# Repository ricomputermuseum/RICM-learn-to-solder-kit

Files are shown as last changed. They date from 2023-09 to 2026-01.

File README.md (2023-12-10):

# RICM-learn-to-solder-kit
These badges were designed as a soldering demo for the Rhode Island Computer Museum (RICM). They were designed to teach the basics of thru-hole soldering, as well as to provide users with a take home wearable. 
 
## Goals for this kit:
* A beginner kit for learning to solder.
* A simple circuit, 2 LEDS and a battery, but still interactive.
* Low cost, suitable for scout troops, school classes, summer camps, etc. Depending on order volume, parts will cost $2-4 per badge.

## Assembly instructions:
1. Solder the battery clip onto the exposed pads on the back of the board. Note that the battery clip used in this design is surface mount and considerably more difficult to solder than the other components. Depending on the audience it may be desirable for the instructor to solder this component before passing them out. 
2. Flip the board over and solder all other components to the front. Resistor values and transistor orientation are printed on the silkscreen.
3. Insert battery into clip and turn on switch. Hold hand over photoresistor to light up LEDS

## Parts list:
1x printed circuit board.
1x 47KΩ resistor (1/4W 5% carbon-film)
2x 220Ω resistors (1/4W 5% carbon-film)
1x NPN transistor (2N3904 or similar NPN (BC547,2N2222 etc.), TO-92-3 Kinked Lead)
2x light-emitting diodes (5mm, any color as desired)
1x SPDT mini slide switch (Shouhan SS-12D07VG3 or similar)
1x battery holder (Keystone 3002, 20mm coin cell, surface mount)
1x CR2032 Battery (3V, 20x3.2mm, 200mA)

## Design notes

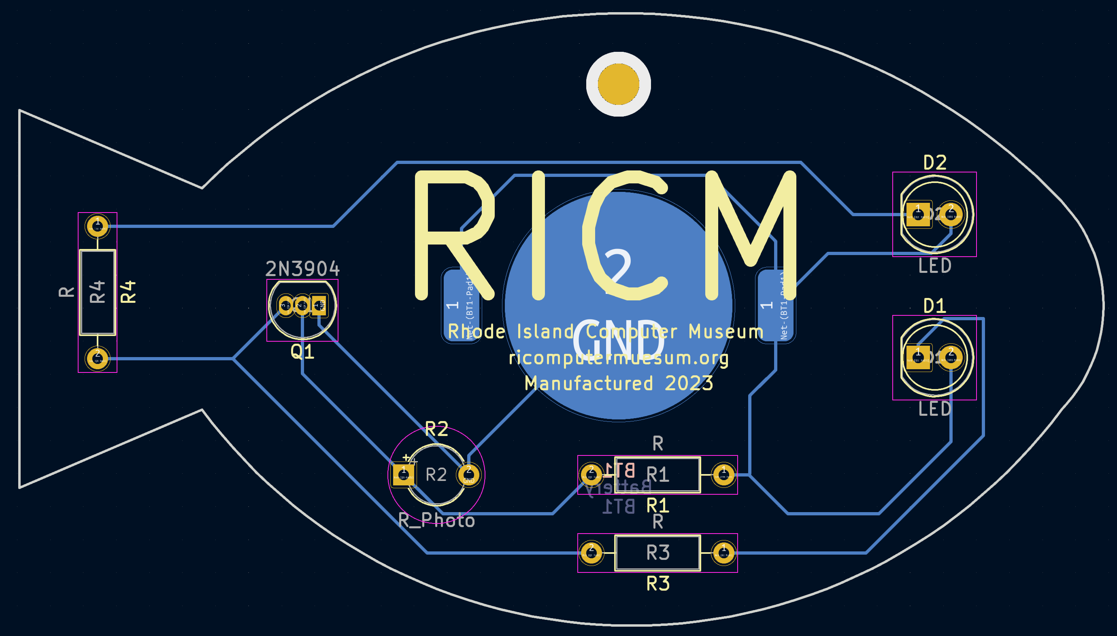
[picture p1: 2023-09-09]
image.png

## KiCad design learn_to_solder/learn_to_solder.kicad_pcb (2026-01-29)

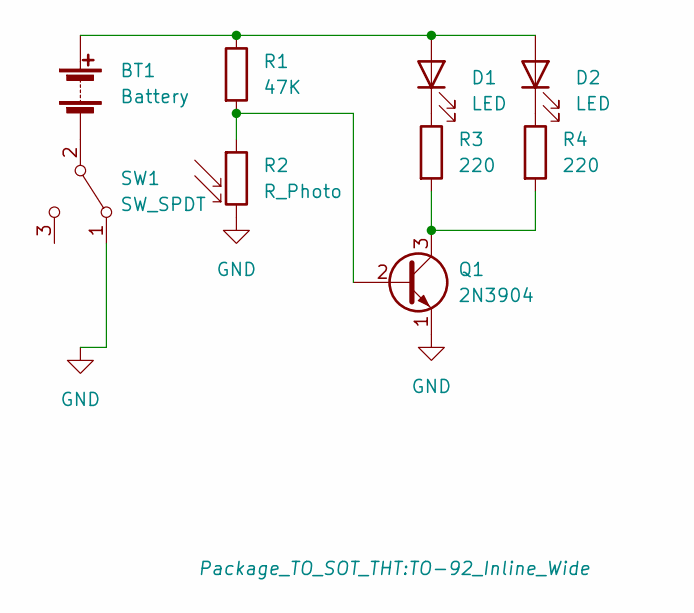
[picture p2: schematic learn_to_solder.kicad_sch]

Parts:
BT1: Battery; CR2032 retainer
D1, D2: LED; LED_D5.0mm
Q1: 2N3904; TO-92_Inline_Wide
R1: 47K; R_Axial_DIN0207_L6.3mm_D2.5mm_P10.16mm_Horizontal
R2: R_Photo; CP_Radial_Tantal_D4.5mm_P5.00mm
R3, R4: 220; R_Axial_DIN0207_L6.3mm_D2.5mm_P10.16mm_Horizontal
SW1: SW_SPDT; SW_Slide_1P2T_CK_OS102011MS2Q

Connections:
GND: Q1.1 (E), R2.2, SW1.1 (A)
unnamed: BT1.1 (+), D1.2 (A), D2.2 (A), R1.1
unnamed: BT1.2 (-), SW1.2 (B)
unnamed: D1.1 (K), R3.1
unnamed: D2.1 (K), R4.1
unnamed: Q1.2 (B), R1.2, R2.1
unnamed: Q1.3 (C), R3.2, R4.2

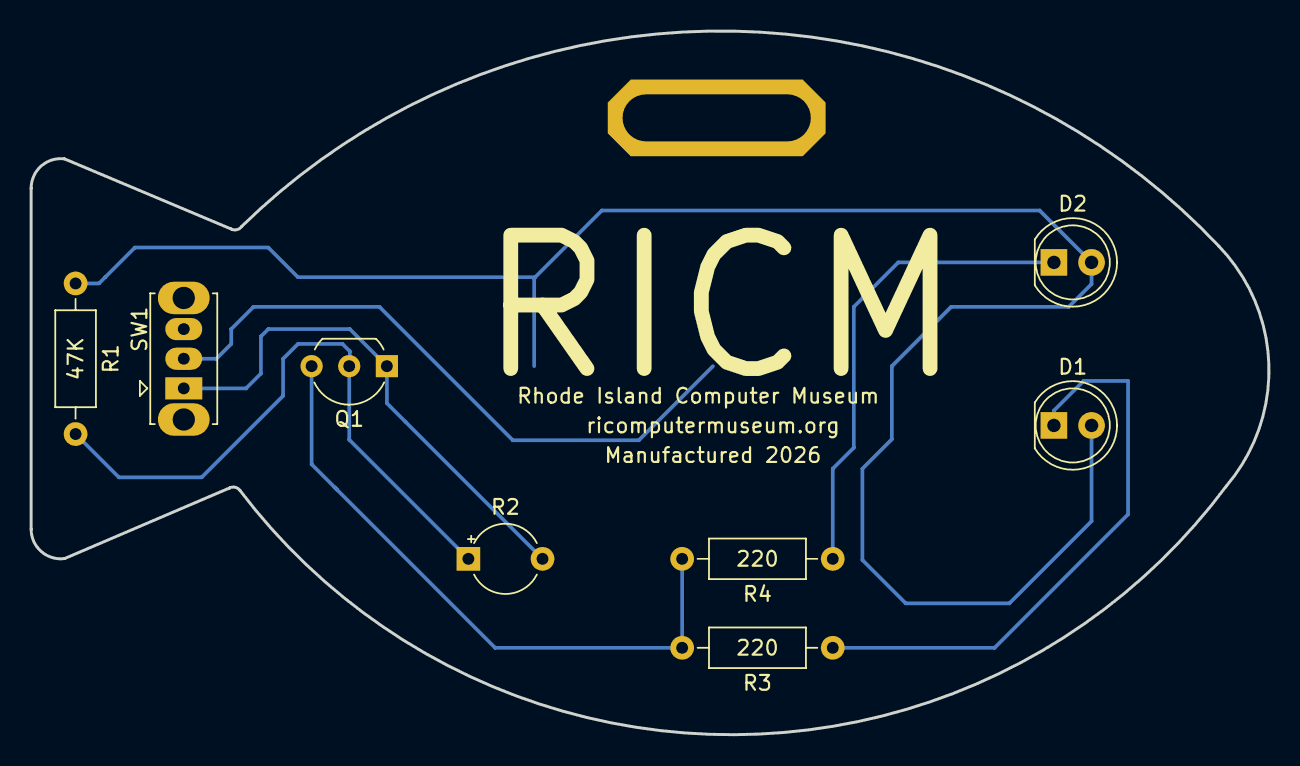
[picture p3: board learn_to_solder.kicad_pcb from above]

Board: 2 copper layers, 83.5 x 47.5 mm, 9 parts (1 on the bottom side), 7 nets.

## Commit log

2023-09-08 Added kicad files for first draft
    [learn_to_solder.kicad_pcb, learn_to_solder.kicad_sch]
2023-09-09 Create README.md
    RICM Learn to Solder Badge
2023-09-22 plotted gerbers
    [learn_to_solder_shrimp.kicad_pcb, learn_to_solder_shrimp.kicad_sch]
2023-09-22 Updated readme and silkscreen
    Updated readme to correctly reflect kit components. Added labels in front silkscreen with resistor values to make assembly easier. Rearranged resistors to put both 220s next to each other.
    [learn_to_solder.kicad_pcb, learn_to_solder.kicad_sch, learn_to_solder_shrimp.kicad_pcb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]
2023-12-10 V2 updates
    Rearranged resistors to group both 220s together. Added slide switch to turn off without removing battery. Corrected typos in silkscreen. Fixed clip slot size.
    [learn_to_solder.kicad_pcb, learn_to_solder.kicad_sch]
2026-01-29 v3 edits
    Filleted sharp board edge. Added slot footprint for hanger.
    [learn_to_solder-B_Cu.gbr, learn_to_solder-B_Mask.gbr, learn_to_solder-B_Paste.gbr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]
